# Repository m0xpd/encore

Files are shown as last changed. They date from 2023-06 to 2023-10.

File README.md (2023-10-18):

# encore!
An Echo/Delay Module for Eurorack, based on the PT2399

<p width=100%, align="center">

</p>

This repository describes a delay module, developed for electronic synthesisers, in Eurorack format, based on the [Princeton Technology](http://www.princeton.com.tw/en-us/products.aspx) [PT2399](http://www.princeton.com.tw/LinkClick.aspx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) device. 

**Functional Description**

A block diagram of  encore!  is shown below:

<p width=100%, align="center">

</p>  

The module uses the PT2399 in an application environment derived from circuits in the [datasheet](http://www.princeton.com.tw/LinkClick.aspx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), but adds resources to enable patching and use in the Eurorack environment. 
These resources are described below.

In addition to the filtering already suggested in the application circuit and supported by the PT2399's integral amplifiers, encore! adds a 2nd order 
input filter and a 4th order output filter in Butterworth configuration. 

Unlike most simple PT2399 delay circuits, which are adjusted by potentiometers, encore! places the key parameters of Delay Length, Repeats (i.e. the gain 
of the recursion/feedback loop) and Level of the 'Wet' signal under voltage control, allowing parameter adjustment by potentiometers and/or CV inputs. 

In the case of the Delay Length, this is achieved by a Voltage Controlled Resistor circuit. 

In the case of the other two parameters, this is achieved by Voltage Controlled Amplifiers.  

Most significantly, encore! allows the user to patch external functions into the feedback/recursion loop that builds the echo (seen in the red dashed box in 
the block diagram above), using a loop send / return feature, which is mixed with the module's internal feedback path. This allows (e.g.) filters to be inserted 
to allow selective echos, multiple delay units to be cross-patched to build up complex echo strutures, etc..

**Licensing**

encore! is published under a Creative Commons BY-SA 4.0 [License](https://github.com/m0xpd/encore/blob/main/LICENSE.txt)

**Implementation**

The system is implemented on two PCBs; one for the main electronics and one for the controls and interface components.

The schematic for the main PCB is linked by the graphic below below (click for the full-size schematic):

<p width=100%, align="center">

</p>  

I should have put a buffer between the PT2399 output filters and the input to the 'output filter' (which doesn't have a very high input impedance), but I 
didn't have any spare op-amp stages. I can live with the loading interactions as they are!

The schematic for the control PCB is linked below:

<p width=100%, align="center">

</p>  

The two PCBs are joined electrically and mechanically by the 'Board interface', implemented as two 20-way headers (JP1 and JP2 in the schematics, male on the
 main board and female on the control board). A BoM for the main board is included.

You will find full details of the two printed circuit boards (in files for the Eagle Layout Editor) [here](https://github.com/m0xpd/encore/tree/main/PCBs) and 
a Kicad project defining a front panel [here](https://github.com/m0xpd/encore/tree/main/FrontPanel).

**Specifications**

encore! is 12HP wide and extends 38mm behind the front panel (when a standard Eurorack power header is inserted).

Caution: I've just been reminded (thanks Alex) that the PCBs of the present design overhang the left hand edge of the front panel by approximately 1mm. This 
is **an error on my part**, which I'll correct if ever there's a new 'edition' of encore! Multiple instances of encore! sit next to each other in a rack with 
no worries, but don't try to sit encore! next to a neighbour on its left which doesn't leave sufficient space.

encore! draws 36.5 mA from the +12V rail, 12.5 mA from the -12V rail, and nothing from the 5V rail.

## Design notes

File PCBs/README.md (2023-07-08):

# Printed Circuit Boards

This folder contains details of the two PCBs required to implement the encore! delay module.

The PCB design files are presented in Eagle format.

Below you see a photo of the unpopulated PCBs.

The photo shows (left to right) the Main Board Component Side (Top), Main Board Bottom, Control Board Component Side (Top), and Control Board Bottom. 

<p width=100%, align="center">

</p>  

Images of the main board on this repository are currently of a v1 protoype which included an error (a missing resistor), which is corrected in the design files.

## Main Board Capacitors 

The [BoM](https://github.com/m0xpd/encore/blob/main/PCBs/encore%20Main%20Board%20v2%20BoM.txt) is presented in the standard EAGLE format, which is verbose and not always helpful. A description of the capacitors used on the main board is given 
below (refer to the [schematic](https://user-images.githubusercontent.com/3152962/246648781-e0986f40-e248-4756-a811-1461d0e43b70.png) for component idents).

De-coupling capacitors C1, C2, C12, C13, C9, C20, C21 and modulate/de-modulate capacitors for the PT2399, C23, C24, C30, C32 (all having value quoted as 
“0.1u” in the BoM) are disc ceramics with 0.2-inch pitch.

Filter / coupling capacitors (C5, C7, C8, C14, C15, C16, C17, C18, C19, C25, C27, C28, C31, C33) are ceramics (for pF values), or multi-layer ceramics 
(for nF values), most of which have 0.1-inch pitch (except C7, C9, C27 & C33, where I used 0.2-inch pitch components for my own convenience). 

Polarized capacitors with 0.1-inch pitch are used for power supply smoothing (C3, C4, C10, C11), smoothing the mid-rail voltage of the PT2399 (C22) and 
d.c. blocking (C26, C29).

There is NO C6, due to an indexing error on my part.

## Control Board Components

Certain components on the control board have mechanical as well as electrical significance.

VR2 VR3 and VR4 are 9mm Vertical Alpha potentiometers [such as these](https://www.thonk.co.uk/shop/alpha-9mm-pots-vertical-t18/)

SK1:SK10 are [Thonkiconn](https://www.thonk.co.uk/shop/thonkiconn/) 3.5mm jack sockets

The combination of the alpha potentiometers and the Thonkiconn jacks gives the correct spacing between the Control Board and the Front Panel.

VR1 and VR5 are Song Huei 9mm Trim Pots, such as [these](https://www.thonk.co.uk/shop/ttpots/)

## Control Board 5V Power

5V is required on the Control Board for the derivation of control voltages via VR2:4 and the limiting of externally applied CVs via the Schottky diodes D1:6.

I did not want to use the PT2399's 5V supply in this application and found it convenient to generate 5V using a 78L05 regulator ("IC1") from the 12V rail, 
even though a much simpler circuit could have been used. Laziness rules! 

## Board Interface

Electrical and Mechanical Interface between the Main and Control Boards is achieved using 20-way 0.1-inch headers (JP1 & JP2). These are preferably a 
male component on the Main Board and a female component on the Control Board. I find it convenient to buy packs of 40-way headers and cut down to size.

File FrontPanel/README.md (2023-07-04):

# Front Panel

This folder contains a simple Kicad project to create a front panel for the encore! delay module.

<p width=100%, align="center">

</p>  

The panel you see above was manufactured by [JLCPCB](https://jlcpcb.com/) (usual disclaimer) directly from the Gerbers generated by my design files.
It is aluminium and I specified black PCB, with white top screen (for the lettering). Other lines and annotation on the front 
are on the front mask layer.

There is a small text area on the bottom screen (the 'back' of the panel), which - importantly - includes a locator for the order 
number. Remember to select 'specify position' for the order number if you order from JLCPCB, otherwise they might place a meaningless 
number right over the front of your nice panel!

[JLCPCB](https://jlcpcb.com/) do a really good job of making the PCBs and (particularly) these front panels BUT there has been a >350% price increase on the panels since 
the last batch they made for me (for the [SubHarmonic Generator](https://github.com/m0xpd/SubHarmonics) ). If you want pretty, black panels, I 
guess you have to pay.

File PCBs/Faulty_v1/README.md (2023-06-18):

This folder contains details of the FAULTY version 1 Main PCB for the encore! delay module. 

It should NOT be used in new builds and is provided for reference only.

Work-around to correct the fault on the board is achieved by breaking a trace on the top copper (shown by the yellow dashes) and adding a 10k resistor between
'A' and 'B' :

<p width=100%, align="center">

</p>

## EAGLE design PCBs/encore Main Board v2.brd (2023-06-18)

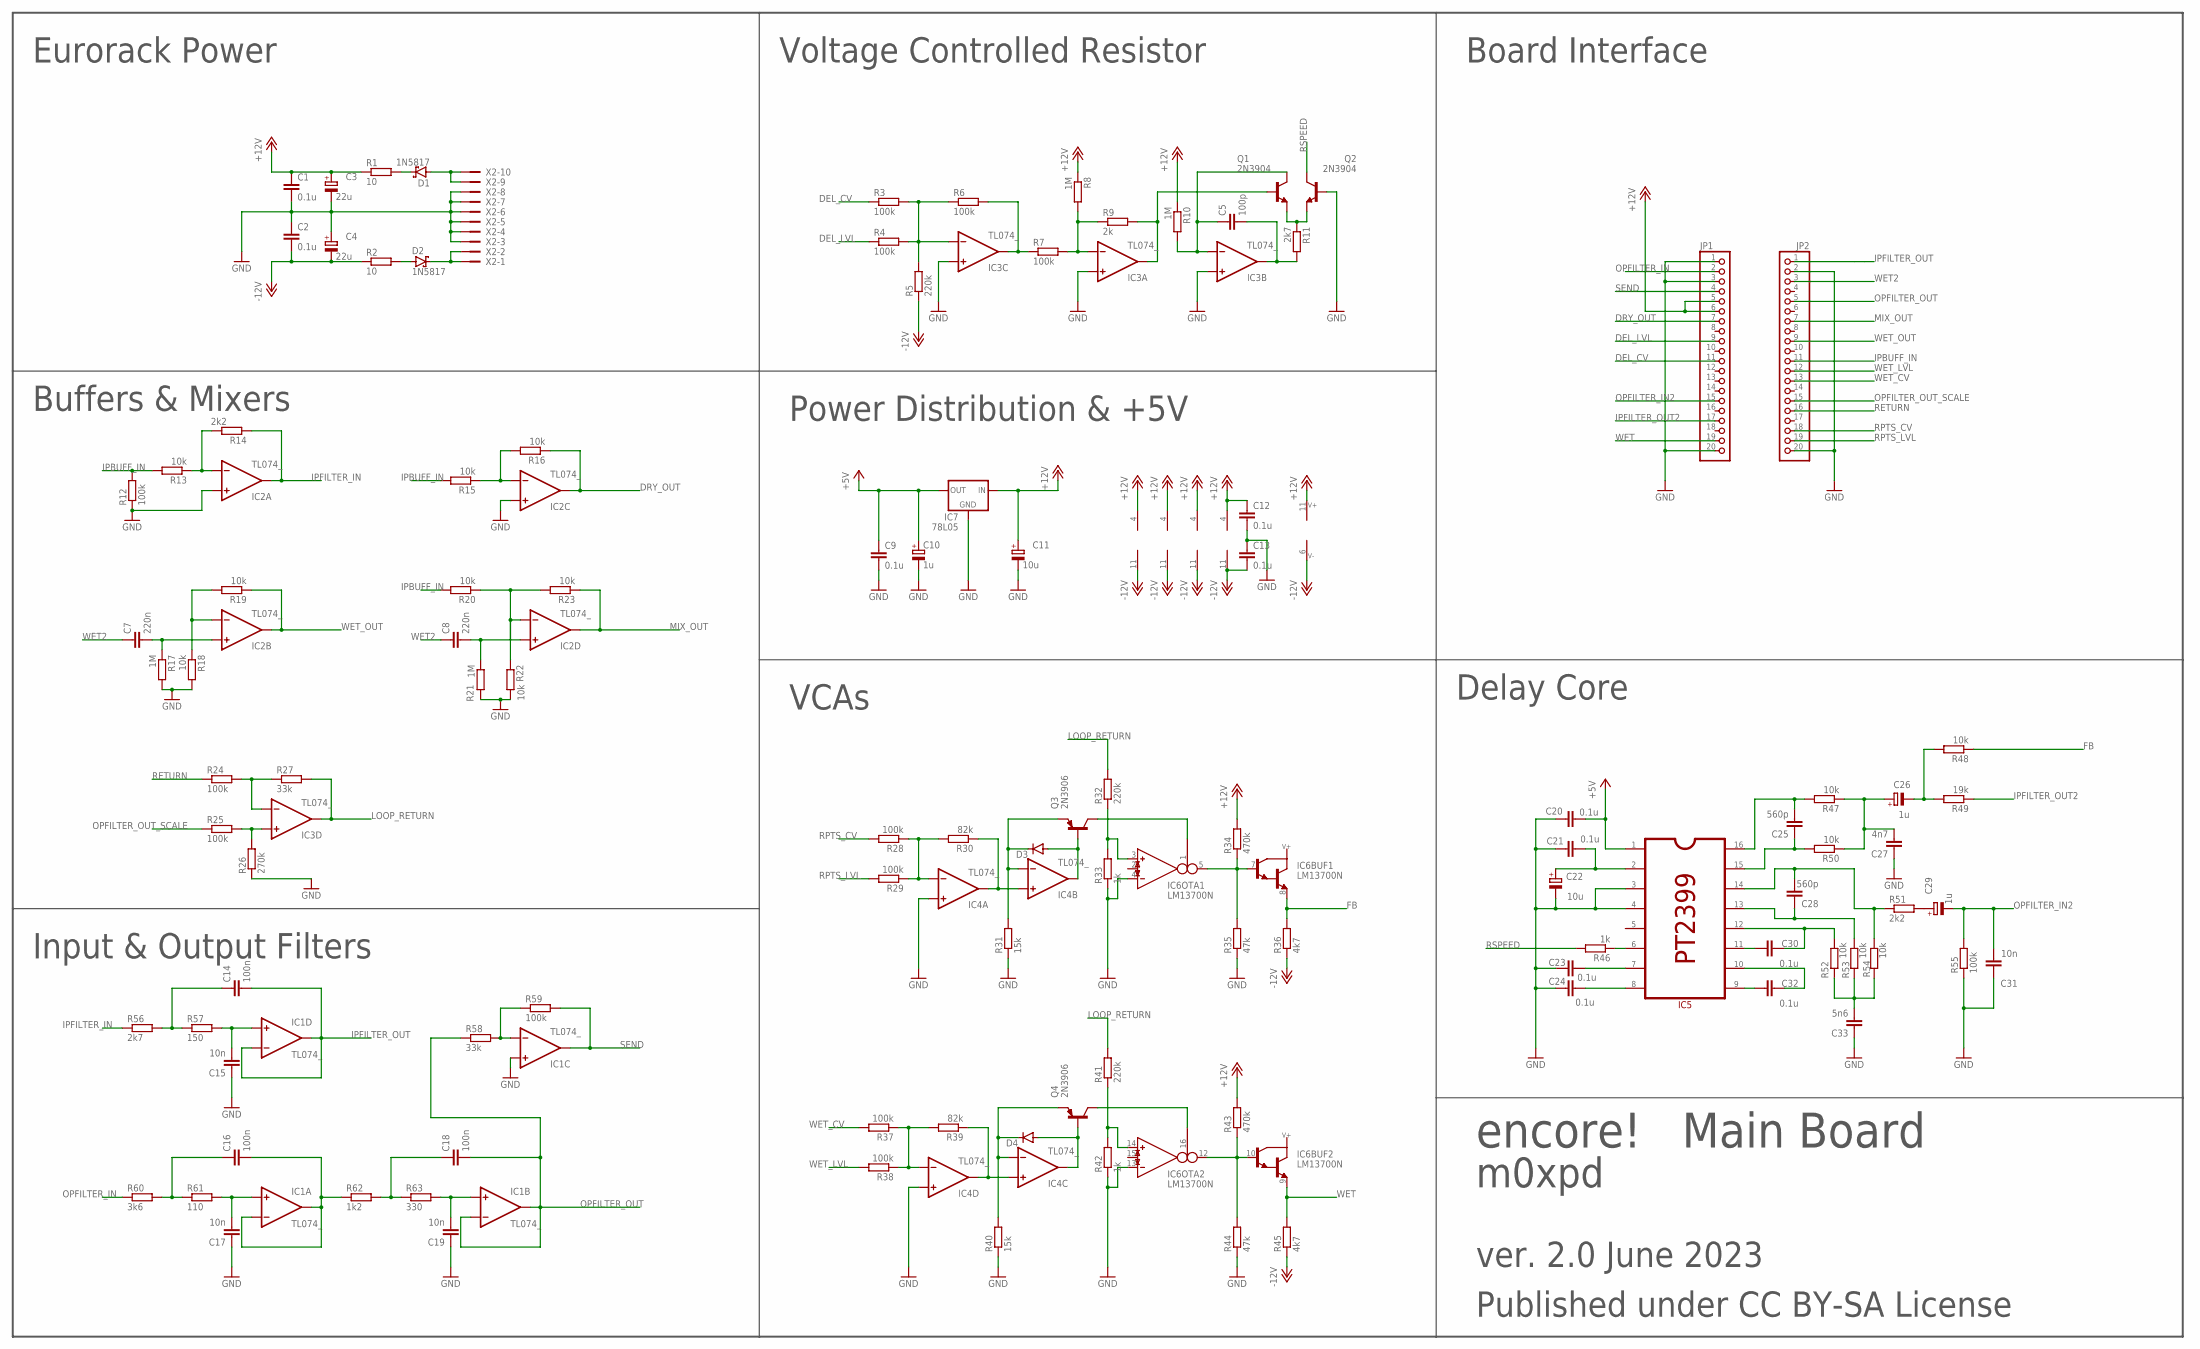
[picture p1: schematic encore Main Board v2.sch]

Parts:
C1, C2, C9, C12, C13, C20, C21, C23, C24, C30, C32: 0.1u; C050-025X075
C3, C4: 22u; E2,5-5
C5: 100p; C025-025X050
C7, C8: 220n; C050-024X044
C10, C26, C29: 1u; E2,5-5
C11, C22: 10u; E2,5-5
C14, C16, C18: 100n; C025-025X050
C15, C17, C19, C31: 10n; C025-025X050
C25, C28: 560p; C025-025X050
C27: 4n7; C050-025X075
C33: 5n6; C050-025X075
D1, D2: 1N5817; DO35-7
D3, D4: 1N4148DO35-7; DO35-7
IC1, IC2, IC3, IC4: TL074_; DIL14
IC5: PT2399; DIP-16
IC6: LM13700N; DIL16
IC7: 78L05; 78LXX
JP1, JP2: PINHD-1X20; 1X20
Q1, Q2: 2N3904; TO92
Q3, Q4: 2N3906; TO92
R1, R2: 10; 0204/7
R3, R4, R6, R7, R12, R24, R25, R28, R29, R37, R38, R55, R59: 100k; 0204/7
R5, R32, R41: 220k; 0204/7
R8, R10, R17, R21: 1M; 0204/7
R9: 2k; 0204/7
R11, R56: 2k7; 0204/7
R13, R15, R16, R18, R19, R20, R22, R23, R47, R48, R50, R52, R53, R54: 10k; 0204/7
R14, R51: 2k2; 0204/7
R26: 270k; 0204/7
R27, R58: 33k; 0204/7
R30, R39: 82k; 0204/7
R31, R40: 15k; 0204/7
R33, R42, R46: 1k; 0204/7
R34, R43: 470k; 0204/7
R35, R44: 47k; 0204/7
R36, R45: 4k7; 0204/7
R49: 19k; 0204/7
R57: 150; 0204/7
R60: 3k6; 0204/7
R61: 110; 0204/7
R62: 1k2; 0204/7
R63: 330; 0204/7
X2: 2510-; PAK100/2500-10

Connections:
+5V: C9.1, C10.+, C20.2, IC5.1, IC7.OUT
+12V: C1.1, C3.+, C11.+, C12.1, IC1.4 (V+), IC2.4 (V+), IC3.4 (V+), IC4.4 (V+), IC6.11 (V+), IC7.IN, JP1.5, JP1.6, R1.1, R8.1, R10.1, R34.2, R43.2
-12V: C2.2, C4.-, C13.2, IC1.11 (V-), IC2.11 (V-), IC3.11 (V-), IC4.11 (V-), IC6.6 (V-), R2.1, R5.1, R36.1, R45.1
DEL_CV: JP1.11, R3.1
DEL_LVL: JP1.9, R4.1
DRY_OUT: IC2.8 (OUT), JP1.7, R16.1
FB: IC6.8 (E), R36.2, R48.1
GND: C1.2, C2.1, C3.-, C4.+, C9.2, C10.-, C11.-, C12.2, C13.1, C15.1, C17.1, C19.1, C20.1, C21.1, C22.-, C23.1, C24.1, C27.1, C31.1, C33.1, IC1.10 (+IN), IC2.3 (+IN), IC2.10 (+IN), IC3.3 (+IN), IC3.5 (+IN), IC3.10 (+IN), IC4.3 (+IN), IC4.12 (+IN), IC5.3, IC5.4, IC6.4 (IN_N), IC6.13 (IN_N), IC7.GND, JP1.1, JP1.3, JP1.20, JP2.2, JP2.20, Q2.2 (B), R12.1, R17.2, R18.2, R21.2, R22.2, R26.1, R31.1, R33.1, R35.1, R40.1, R42.1, R44.1, R55.1, X2.3, X2.4, X2.5, X2.6, X2.7, X2.8
IPBUFF_IN: JP2.11, R12.2, R13.2, R15.2, R20.2
IPFILTER_IN: IC2.1 (OUT), R14.1, R56.1
IPFILTER_OUT: C14.2, IC1.13 (-IN), IC1.14 (OUT), JP2.1
IPFILTER_OUT2: JP1.17, R49.1
LOOP_RETURN: IC3.14 (OUT), R27.2, R32.2, R41.2
MIX_OUT: IC2.14 (OUT), JP2.7, R23.1
unnamed: IC3.1 (OUT), Q1.2 (B), R9.2
unnamed: C15.2, IC1.12 (+IN), R57.2
unnamed: C5.1, IC3.6 (-IN), Q1.1 (C), R10.2
unnamed: C14.1, R56.2, R57.1
unnamed: C16.2, IC1.1 (OUT), IC1.2 (-IN), R62.1
unnamed: C16.1, R60.2, R61.1
unnamed: C17.2, IC1.3 (+IN), R61.2
unnamed: C5.2, IC3.7 (OUT), R11.2
unnamed: Q1.3 (E), Q2.3 (E), R11.1
unnamed: C18.1, R62.2, R63.1
unnamed: C19.2, IC1.5 (+IN), R63.2
unnamed: IC2.2 (-IN), R13.1, R14.2
unnamed: D1.A, X2.9, X2.10
unnamed: D1.C, R1.2
unnamed: C26.-, R48.2, R49.2
unnamed: IC2.6 (-IN), R18.1, R19.2
unnamed: C21.2, C22.+, IC5.2
unnamed: IC1.9 (-IN), R58.2, R59.1
unnamed: IC6.5 (OUT), IC6.7 (B), R34.1, R35.2
unnamed: C7.2, IC2.5 (+IN), R17.1
unnamed: IC3.12 (+IN), R25.2, R26.2
unnamed: C32.2, IC5.10
unnamed: IC6.3 (IN_P), R32.1, R33.2
unnamed: D3.A, IC4.7 (OUT), Q3.2 (B)
unnamed: D3.C, IC4.6 (-IN), Q3.3 (E), R31.2
unnamed: D2.A, R2.2
unnamed: D2.C, X2.1, X2.2
unnamed: IC6.1 (I_BIAS), Q3.1 (C)
unnamed: IC4.1 (OUT), IC4.5 (+IN), R30.1
unnamed: IC5.6, R46.1
unnamed: IC4.2 (-IN), R28.1, R29.1, R30.2
unnamed: IC4.10 (+IN), IC4.14 (OUT), R39.1
unnamed: IC6.10 (B), IC6.12 (OUT), R43.1, R44.2
unnamed: IC6.16 (I_BIAS), Q4.1 (C)
unnamed: IC6.14 (IN_P), R41.1, R42.2
unnamed: D4.C, IC4.9 (-IN), Q4.3 (E), R40.2
unnamed: D4.A, IC4.8 (OUT), Q4.2 (B)
unnamed: IC3.2 (-IN), R7.2, R8.2, R9.1
unnamed: IC4.13 (-IN), R37.1, R38.1, R39.2
unnamed: IC3.8 (OUT), R6.2, R7.1
unnamed: C23.2, IC5.7
unnamed: IC3.9 (-IN), R3.2, R4.2, R5.2, R6.1
unnamed: C24.2, IC5.8
unnamed: C25.2, IC5.16, R47.2
unnamed: C25.1, IC5.15, R50.2
unnamed: C26.+, C27.2, R47.1, R50.1
unnamed: C32.1, IC5.9
unnamed: C28.2, IC5.14, R51.1, R54.1
unnamed: C28.1, IC5.13, R53.1
unnamed: C30.1, IC5.11
unnamed: C30.2, IC5.12, R52.1
unnamed: C33.2, R52.2, R53.2, R54.2
unnamed: C29.+, R51.2
unnamed: C8.2, IC2.12 (+IN), R21.1
unnamed: IC2.13 (-IN), R20.1, R22.1, R23.2
unnamed: IC3.13 (-IN), R24.2, R27.1
unnamed: IC2.9 (-IN), R15.1, R16.2
OPFILTER_IN: JP1.2, R60.1
OPFILTER_IN2: C29.-, C31.2, JP1.15, R55.2
OPFILTER_OUT: C18.2, IC1.6 (-IN), IC1.7 (OUT), JP2.5, R58.1
OPFILTER_OUT_SCALE: JP2.15, R25.1
RETURN: JP2.16, R24.1
RPTS_CV: JP2.18, R28.2
RPTS_LVL: JP2.19, R29.2
RSPEED: Q2.1 (C), R46.2
SEND: IC1.8 (OUT), JP1.4, R59.2
WET: IC6.9 (E), JP1.19, R45.2
WET2: C7.1, C8.1, JP2.3
WET_CV: JP2.13, R37.2
WET_LVL: JP2.12, R38.2
WET_OUT: IC2.7 (OUT), JP2.9, R19.1

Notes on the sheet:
encore! Main Board
m0xpd
ver. 2.0 June 2023
Eurorack Power
Input & Output Filters
Buffers & Mixers
VCAs
Voltage Controlled Resistor
Power Distribution & +5V
Board Interface
Delay Core
Published under CC BY-SA License

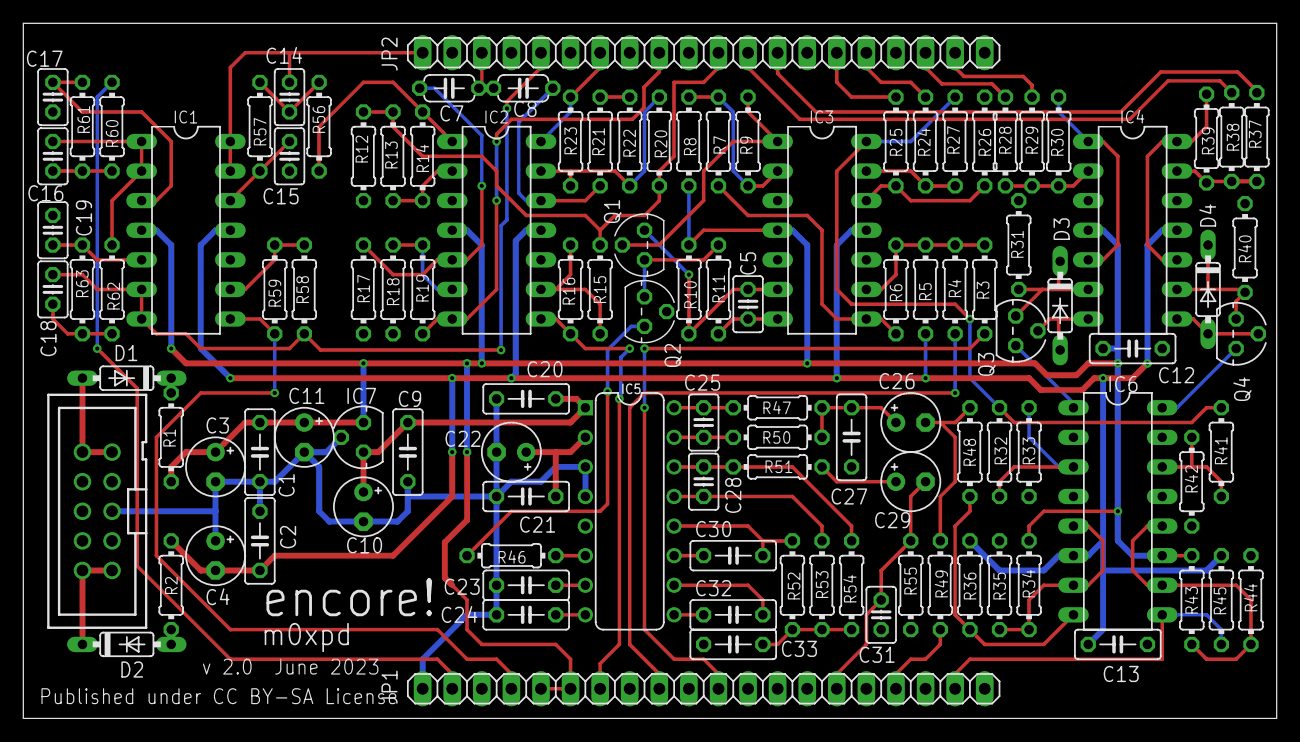
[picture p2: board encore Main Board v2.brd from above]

Board: 2 copper layers, 107.6 x 59.7 mm, 113 parts (0 on the bottom side), 85 nets.

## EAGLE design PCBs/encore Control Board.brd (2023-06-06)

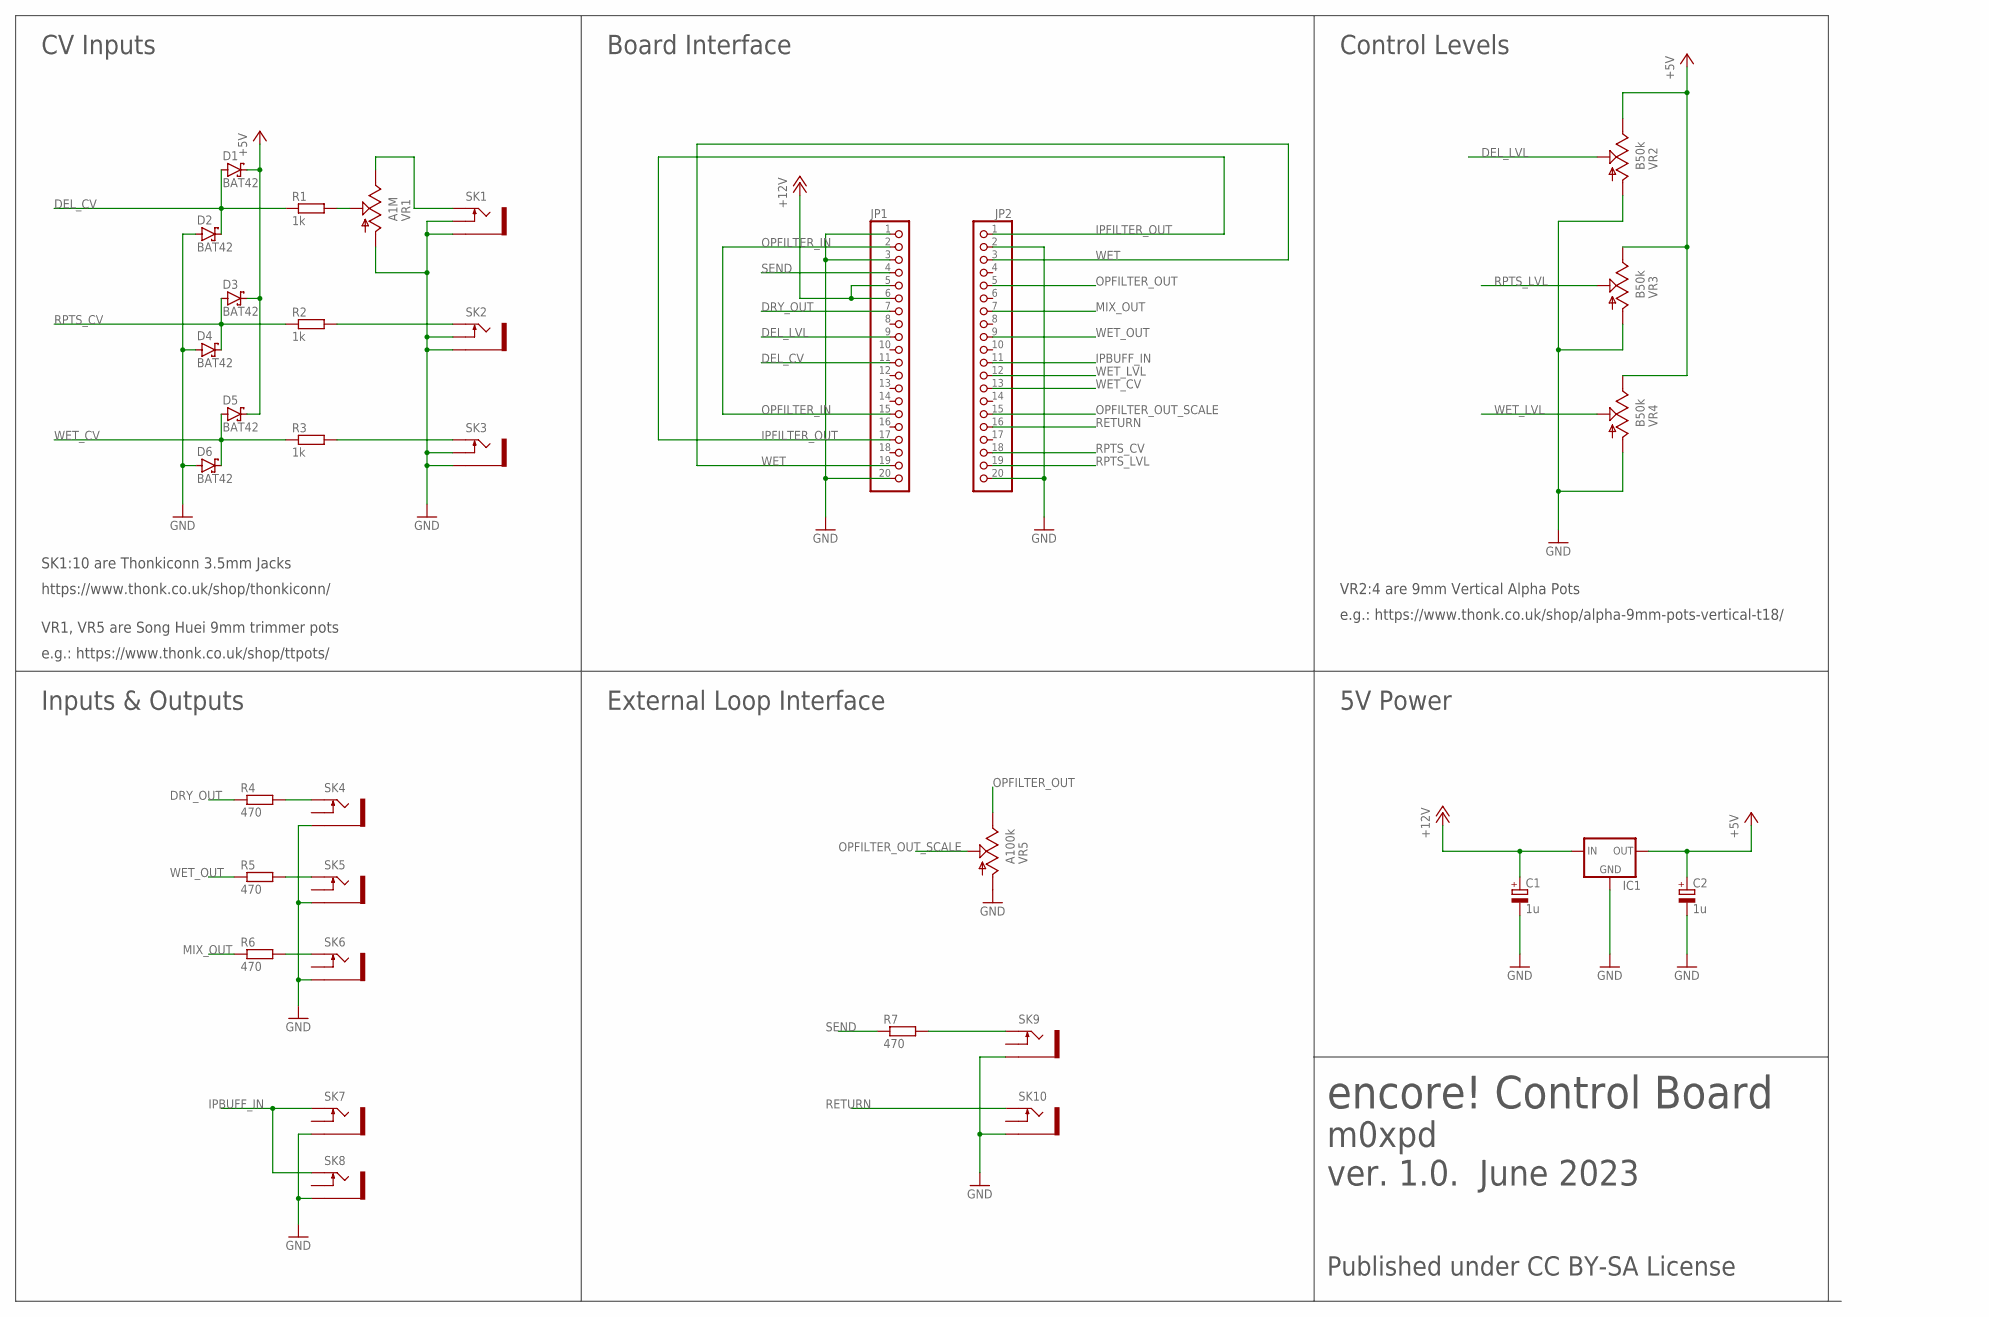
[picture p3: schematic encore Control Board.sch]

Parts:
C1, C2: 1u; E2,5-5
D1, D2, D3, D4, D5, D6: BAT42; DO35-10
IC1: 78LXX
JP1, JP2: PINHD-1X20; 1X20
R1, R2, R3: 1k; 0204/7
R4, R5, R6, R7: 470; 0204/7
SK1, SK2, SK3, SK4, SK5, SK6, SK7, SK8, SK9, SK10: THONKICONN_JACK; WQP-PJ301M-12_JACK
VR1: A1M; 9MM_SNAP-IN_POT
VR2, VR3, VR4: B50k; 9MM_SNAP-IN_POT
VR5: A100k; 9MM_SNAP-IN_POT

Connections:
+5V: C2.+, D1.C, D3.C, D5.C, IC1.OUT, VR2.3 (E), VR3.3 (E), VR4.3 (E)
+12V: C1.+, IC1.IN, JP1.5, JP1.6
DEL_CV: D1.A, D2.C, JP1.11, R1.1
DEL_LVL: JP1.9, VR2.2 (S)
DRY_OUT: JP1.7, R4.1
GND: C1.-, C2.-, D2.A, D4.A, D6.A, IC1.GND, JP1.1, JP1.3, JP1.20, JP2.2, JP2.20, SK1.P$2_SWITCH (SWITCH), SK1.P$3_SLEEVE (SLEEVE), SK2.P$2_SWITCH (SWITCH), SK2.P$3_SLEEVE (SLEEVE), SK3.P$2_SWITCH (SWITCH), SK3.P$3_SLEEVE (SLEEVE), SK4.P$3_SLEEVE (SLEEVE), SK5.P$3_SLEEVE (SLEEVE), SK6.P$3_SLEEVE (SLEEVE), SK7.P$3_SLEEVE (SLEEVE), SK8.P$3_SLEEVE (SLEEVE), SK9.P$3_SLEEVE (SLEEVE), SK10.P$3_SLEEVE (SLEEVE), VR1.1 (A), VR2.1 (A), VR3.1 (A), VR4.1 (A), VR5.1 (A)
IPBUFF_IN: JP2.11, SK7.P$1_TIP (TIP), SK8.P$1_TIP (TIP)
IPFILTER_OUT: JP1.17, JP2.1
MIX_OUT: JP2.7, R6.1
unnamed: R4.2, SK4.P$1_TIP (TIP)
unnamed: R5.2, SK5.P$1_TIP (TIP)
unnamed: R6.2, SK6.P$1_TIP (TIP)
unnamed: R7.2, SK9.P$1_TIP (TIP)
unnamed: SK1.P$1_TIP (TIP), VR1.3 (E)
unnamed: R2.2, SK2.P$1_TIP (TIP)
unnamed: R3.2, SK3.P$1_TIP (TIP)
unnamed: R1.2, VR1.2 (S)
OPFILTER_IN: JP1.2, JP1.15
OPFILTER_OUT: JP2.5, VR5.3 (E)
OPFILTER_OUT_SCALE: JP2.15, VR5.2 (S)
RETURN: JP2.16, SK10.P$1_TIP (TIP)
RPTS_CV: D3.A, D4.C, JP2.18, R2.1
RPTS_LVL: JP2.19, VR3.2 (S)
SEND: JP1.4, R7.1
WET: JP1.19, JP2.3
WET_CV: D5.A, D6.C, JP2.13, R3.1
WET_LVL: JP2.12, VR4.2 (S)
WET_OUT: JP2.9, R5.1

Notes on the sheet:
encore! Control Board
m0xpd
ver. 1.0. June 2023
Published under CC BY-SA License
CV Inputs
Board Interface
Control Levels
Inputs & Outputs
External Loop Interface
5V Power
VR2:4 are 9mm Vertical Alpha Pots
e.g.: https://www.thonk.co.uk/shop/alpha-9mm-pots-vertical-t18/
SK1:10 are Thonkiconn 3.5mm Jacks
https://www.thonk.co.uk/shop/thonkiconn/
VR1, VR5 are Song Huei 9mm trimmer pots
e.g.: https://www.thonk.co.uk/shop/ttpots/

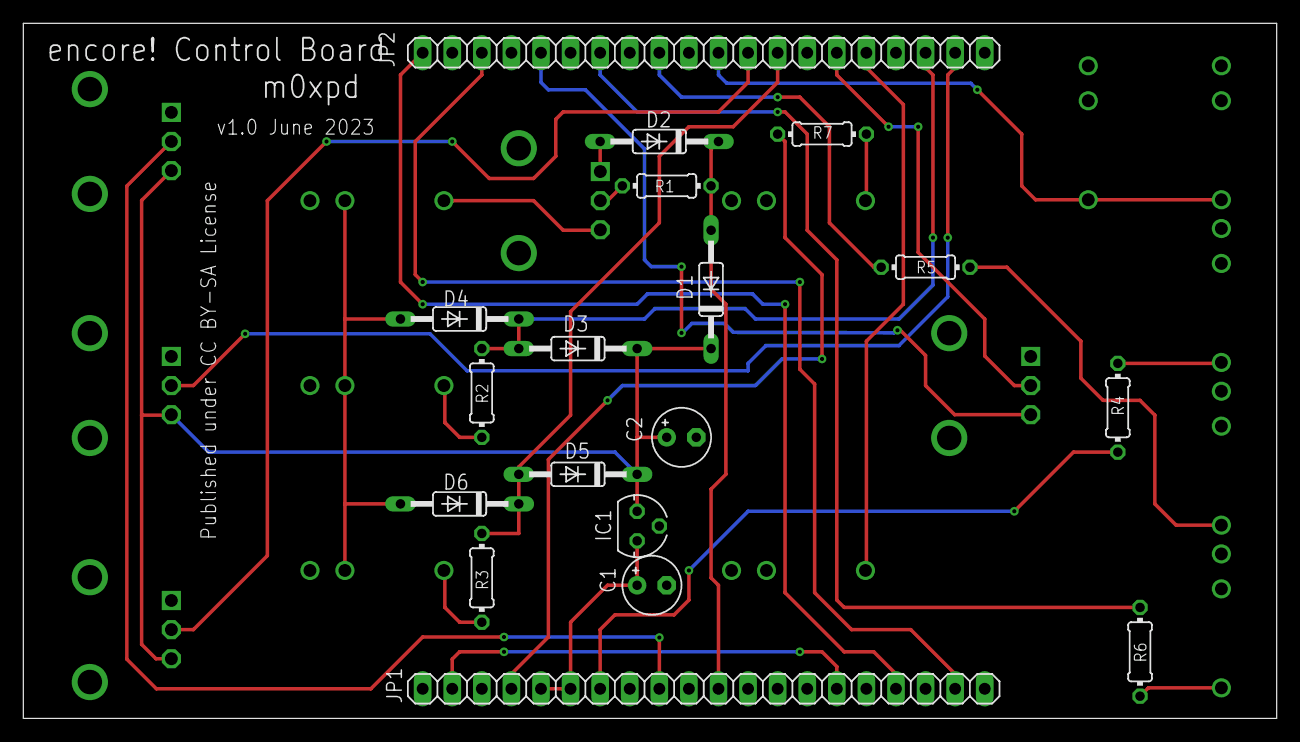
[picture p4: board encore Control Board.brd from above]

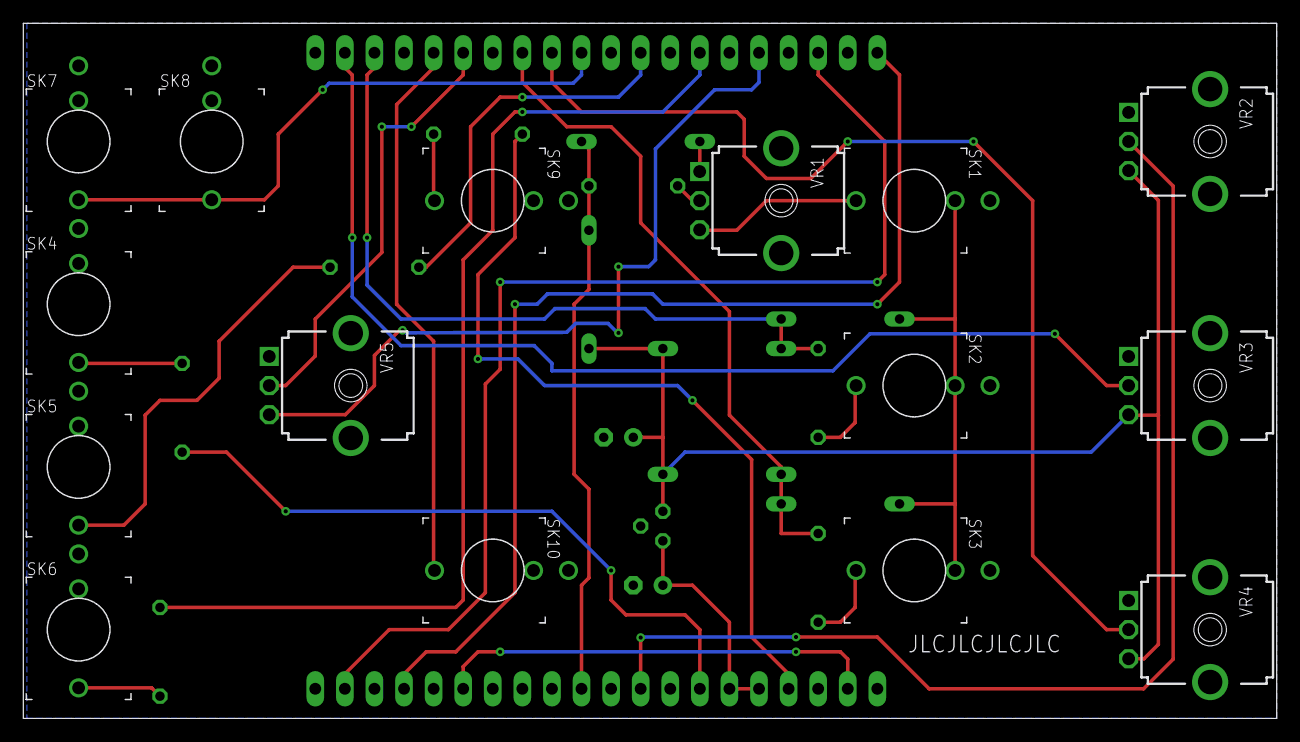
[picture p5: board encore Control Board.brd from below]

Board: 2 copper layers, 107.6 x 59.7 mm, 33 parts (15 on the bottom side), 28 nets.

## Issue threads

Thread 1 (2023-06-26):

no depoupling on the opamps?

KeLaiFu, 2023-06-26:
excuse my noob question, but it seems you didn't include the usual decoupling caps on the opamps (not that I know what that means).

Is there a reason for that in this case or should I add them for 'good practice'?

m0xpd, 2023-06-26:
Thanks for raising this interesting question - which I shall attempt to answer (despite being away from home on vacation, without access to the resources that would make answering easier - like my computer!)

Decoupling is - of course - important and necessary. You will see that I have added four 0.1uF capacitors to decouple the +/- 12V supply (these are, I think, C1, C2, C12 & C13). They are deliberately placed at either ‘end’ of the board.

I have not - however - placed individual decoupling capacitors for each of the four op-amp packages (and the LM13700), having found that the decoupling described above is adequate.

To that extent, I do not always the ‘good-practice’ of placing decoupling on each op-amp when there are multiple op-amps on a board; I suggest the benefits are questionable in certain practical applications.

Your ‘noob’ question needs no excusing; we were all ‘noobs’ once and some of us have the wisdom to be happy to remain ‘noobs’ all our lives!

Thanks for your interest in encore!

Closed 2023-06-26.

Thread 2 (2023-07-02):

Caps all ceramics?

KeLaiFu, 2023-07-02:
Are all the non polarised caps just standard ceramics? There's a variety of different footprints on the board. not sure if the more rectangular ones are normally film caps of its just different sized ceramics?

thanks for the reply on my other question too btw.

m0xpd, 2023-07-04:
Hi again KeLaiFu

Here are details of the capacitors:

De-coupling capacitors C1, C2, C12, C13, C9, C20, C21 and modulate/de-modulate capacitors for the PT2399, C23, C24, C30, C32 (all having value quoted as “0.1u” in the BoM) are disc ceramics with 0.2-inch pitch.

Filter / coupling capacitors (C5, C7, C8, C14, C15, C16, C17, C18, C19, C25, C27, C28, C31, C33) are ceramics (for pF values), or multi-layer ceramics (for nF values) with 0.1-inch pitch.

Polarized capacitors with 0.1-inch pitch are used for power supply smoothing (C3, C4, C10, C11), smoothing the mid-rail voltage of the PT2399 (C22) and d.c. blocking (C26, C29).

There is no 'C6', due to an indexing error on my part.

Thanks for your continued interest in encore!

m0xpd, 2023-07-04:
I added the information above to:
https://github.com/m0xpd/encore/tree/main/PCBs
so everybody can benefit from your useful question.

Closed 2023-07-04.

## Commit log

2023-06-06 Rename encore Control Board.brd to PCBs/encore Control Board.brd
    [encore Control Board.brd]
2023-06-06 Rename encore Control Board.sch to PCBs/encore Control Board.sch
    [encore Control Board.sch]
2023-06-06 Rename encore Main Board.brd to PCBs/encore Main Board.brd
    [encore Main Board.brd]
2023-06-06 Rename encore Main Board.sch to PCBs/encore Main Board.sch
    [encore Main Board.sch]
2023-06-18 Rename PCBs/encore Main Board.sch to PCBs/Faulty_v1/encore Main Board.sch
    [encore Main Board.sch]
2023-06-18 Rename PCBs/encore Main Board.brd to PCBs/Faulty_v1/encore Main Board.brd
    [encore Main Board.brd]
